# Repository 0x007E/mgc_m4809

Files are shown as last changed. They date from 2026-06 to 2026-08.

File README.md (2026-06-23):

  

# `MGC_module` - ATmega4809

The `ATmega4809` (`mgc_module`) is an adaptable board for the [MeGARCard](https://github.com/0x007e/mgc). The board offers the possibility to control the `MeGARCard` with an [ATmega4809](#additional-information). The board itself is connected to the `MeGARCard` within the pcb-to-pcb connectors (no soldering necessary). With the onboard dip-switches the board voltage can be regulated from `3V3` to `5V`. Also the usage of hardware-/software-`twi` to control the [SSD1306](#additional-information)-display on the megacard can be selected.

> To mount the board on the `MeGARCard` disconnect the power source (`USB-C` connector) or any other used source from the MeGARCard!

| Experience  | Level |
|:---|:---:|
| Soldering | ?% |

# Downloads

| Type | File | Description |
|:---:|:---:|:---|
| Schematic | [pdf](https://github.com/0x007E/mgc_m4809/releases/latest/download/schematic.pdf) / [cadlab](https://cadlab.io/project/30419/main/files) | Schematic files |
| Board | [pdf](https://github.com/0x007E/mgc_m4809/releases/latest/download/pcb.pdf) / [cadlab](https://cadlab.io/project/30419/main/files) | Board file |
| Drill | [pdf](https://github.com/0x007E/mgc_m4809/releases/latest/download/drill.pdf) | Drill file |
| BoM | [xlsx](https://github.com/0x007E/mgc_m4809/releases/latest/download/bom.xlsx) / [html](https://github.com/0x007E/mgc_m4809/releases/latest/download/ibom.html) | Bill of Material as Excel/interactive HTML |
| PCB | [zip](https://github.com/0x007E/mgc_m4809/releases/latest/download/kicad.zip) / [tar](https://github.com/0x007E/mgc_m4809/releases/latest/download/kicad.tar.gz) | KiCAD/Gerber/BoM/Drill files |

# Hardware

The pcb is created with `KiCAD`. All files are built with `github actions` so that they are ready for a production environment.

## PCB

The circuit board is populated on both sides (Top, Bottom). The best way for soldering the `SMD` components is within a vapor phase soldering system and for the `THT` components with a standard soldering system.

### Top Layer

Top Layer

### Bottom Layer

Bottom Layer

# Additional Information

| Type | Link | Description |
|:---:|:---:|:---|
| ATmega4809  | [pdf](https://ww1.microchip.com/downloads/en/DeviceDoc/ATmega4808-4809-Data-Sheet-DS40002173A.pdf) | ATmega4808/4809 Data Sheet |
| SSD1306 | [pdf](https://www.vishay.com/docs/37902/oled128o064dbpp3n00000.pdf) | 128 x 64 Graphic OLED |

---

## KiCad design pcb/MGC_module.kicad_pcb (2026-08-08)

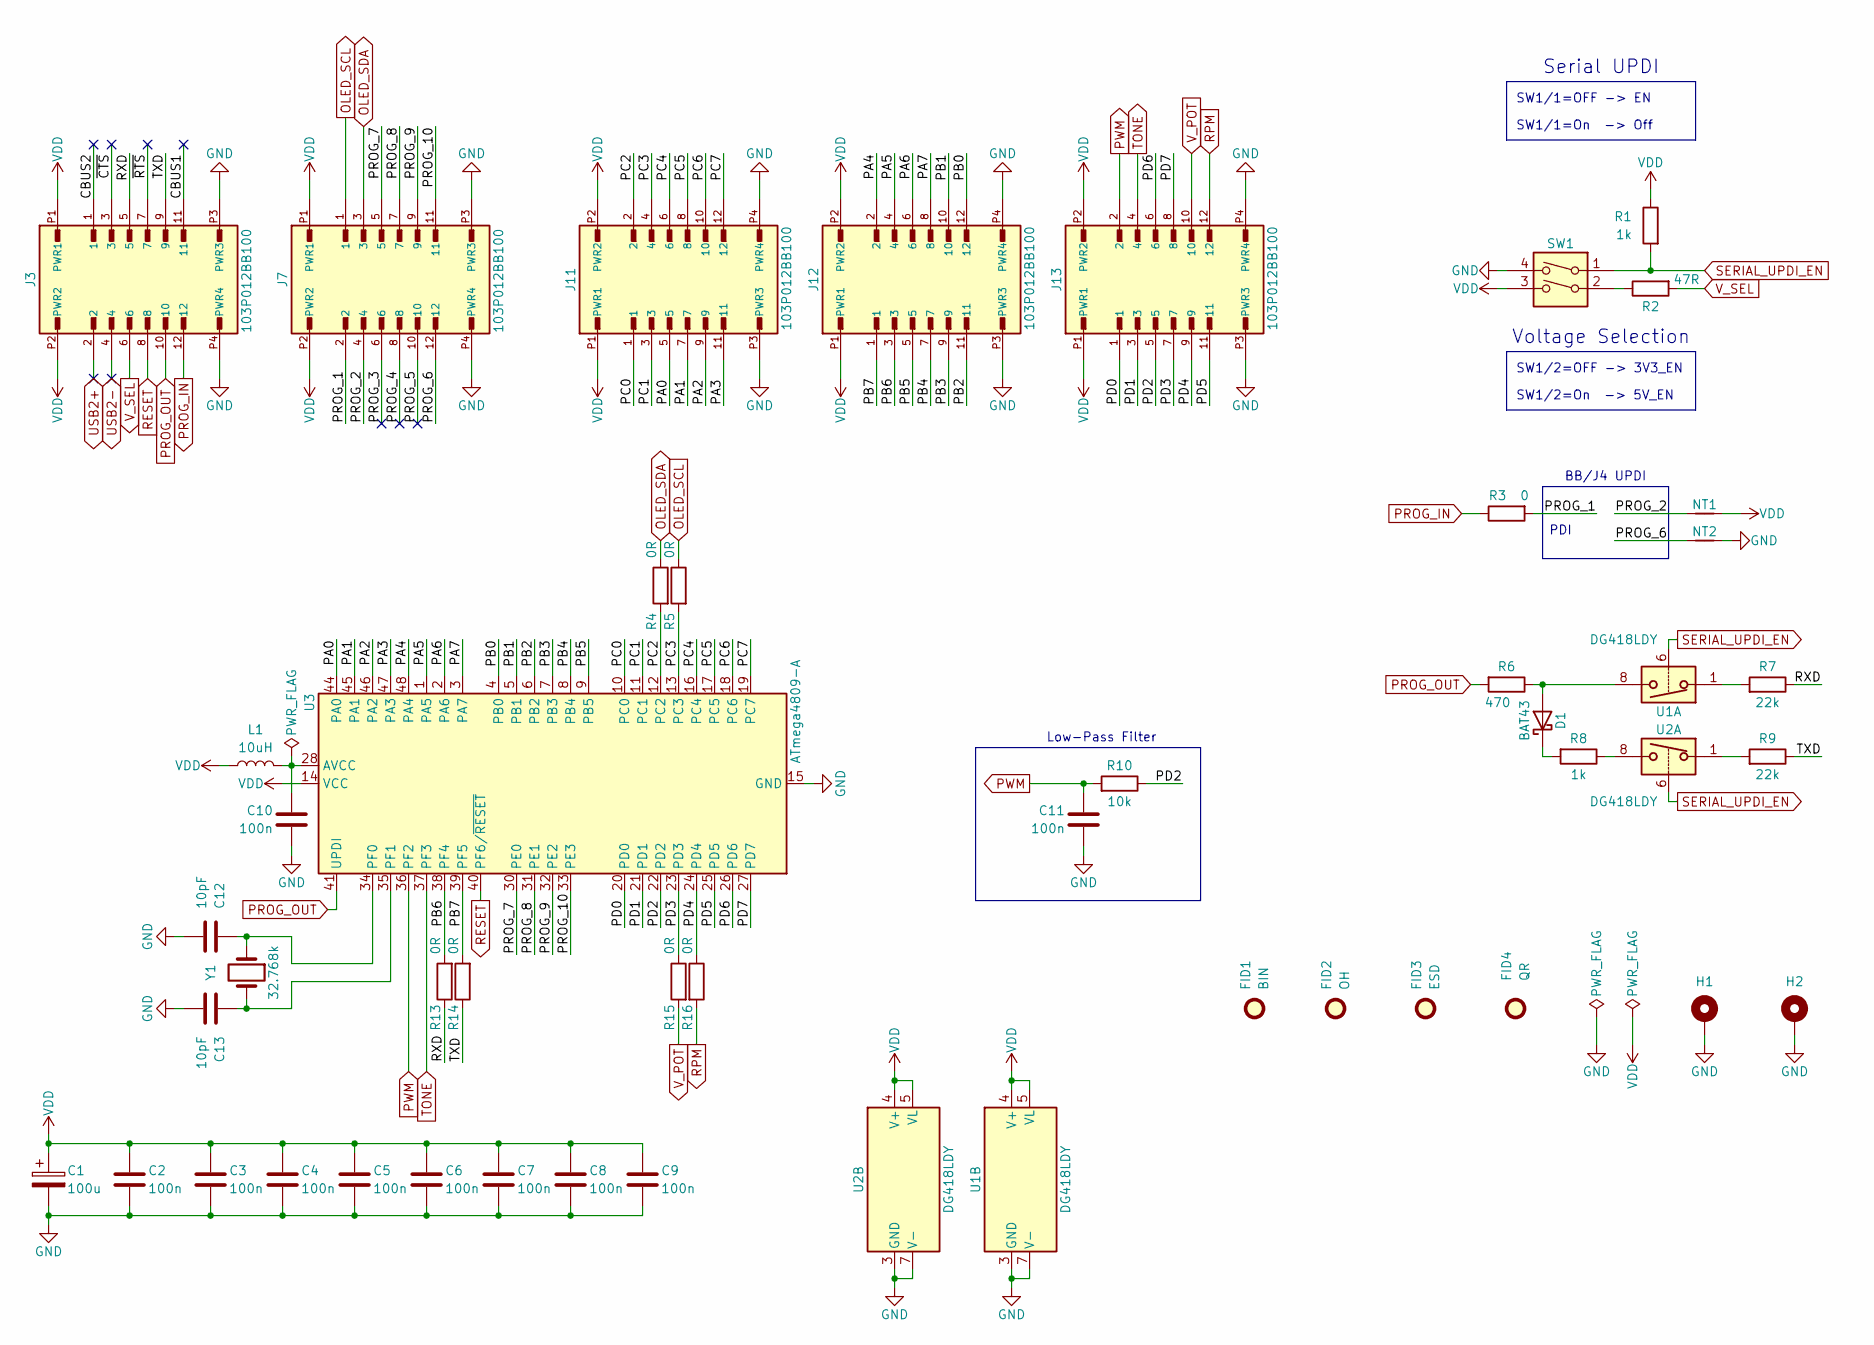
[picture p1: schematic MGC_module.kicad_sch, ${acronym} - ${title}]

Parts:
C1: 100u; CP_EIA-3528-21_Kemet-B; DigiKey 478-3877-1-ND
C2, C3, C4, C5, C6, C7, C8, C9, C10, C11: 100n; C_1206_3216Metric
C12, C13: 10pF; C_0603_1608Metric
D1: BAT43; D_MiniMELF
FID1: BIN; WEEE-Logo_4.2x6mm_SilkScreen
FID2: OH; OSHW-Logo2_7.3x6mm_SilkScreen
FID3: ESD; ESD-Logo_6.6x6mm_SilkScreen
FID4: QR; QR_0x007e_very_small
H1, H2: MountingHole_Pad; MountingHole_2.7mm_M2.5_DIN965_Pad
J3, J7, J11, J12, J13: 103P012BB100; AMPHENOL_103P012BB100; DigiKey 609-103P012BB100CT-ND
L1: 10uH; L_1206_3216Metric
NT1, NT2: NetTie_2; NetTie-2_SMD_Pad0.5mm
R1, R8: 1k; R_1206_3216Metric
R2: 47R; R_1206_3216Metric
R3: 0; R_1206_3216Metric
R4, R5, R13, R14, R15, R16: 0R; R_1206_3216Metric
R6: 470; R_1206_3216Metric
R7, R9: 22k; R_1206_3216Metric
R10: 10k; R_1206_3216Metric
SW1: SW_DIP_x02; SW_DIP_SPSTx02_Slide_6.7x6.64mm_W6.73mm_P2.54mm_LowProfile_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
U1, U2: DG418LDY; SOIC-8_3.9x4.9mm_P1.27mm; DigiKey DG417LEDY-T1-GE4CT-ND
U3: ATmega4809-A; TQFP-48_7x7mm_P0.5mm; DigiKey 150-ATMEGA4809-AURCT-ND
Y1: 32.768k; Crystal_SMD_3215-2Pin_3.2x1.5mm

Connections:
/CBUS1: J3.11
/CBUS2: J3.1
/PA0: J11.5, U3.44 (PA0)
/PA1: J11.7, U3.45 (PA1)
/PA2: J11.9, U3.46 (PA2)
/PA3: J11.11, U3.47 (PA3)
/PA4: J12.2, U3.48 (PA4)
/PA5: J12.4, U3.1 (PA5)
/PA6: J12.6, U3.2 (PA6)
/PA7: J12.8, U3.3 (PA7)
/PB0: J12.12, U3.4 (PB0)
/PB1: J12.10, U3.5 (PB1)
/PB2: J12.11, U3.6 (PB2)
/PB3: J12.9, U3.7 (PB3)
/PB4: J12.7, U3.8 (PB4)
/PB5: J12.5, U3.9 (PB5)
/PB6: J12.3, R13.2, U3.38 (PF4)
/PB7: J12.1, R14.2, U3.39 (PF5)
/PC0: J11.1, U3.10 (PC0)
/PC1: J11.3, U3.11 (PC1)
/PC2: J11.2, R4.2, U3.12 (PC2)
/PC3: J11.4, R5.2, U3.13 (PC3)
/PC4: J11.6, U3.16 (PC4)
/PC5: J11.8, U3.17 (PC5)
/PC6: J11.10, U3.18 (PC6)
/PC7: J11.12, U3.19 (PC7)
/PD0: J13.1, U3.20 (PD0)
/PD1: J13.3, U3.21 (PD1)
/PD2: J13.5, R10.1, U3.22 (PD2)
/PD3: J13.7, R15.1, U3.23 (PD3)
/PD4: J13.9, R16.1, U3.24 (PD4)
/PD5: J13.11, U3.25 (PD5)
/PD6: J13.6, U3.26 (PD6)
/PD7: J13.8, U3.27 (PD7)
/PROG_1: J7.2, R3.2
/PROG_2: J7.4, NT1.1
/PROG_3: J7.6
/PROG_4: J7.8
/PROG_5: J7.10
/PROG_6: J7.12, NT2.1
/PROG_7: J7.5, U3.30 (PE0)
/PROG_8: J7.7, U3.31 (PE1)
/PROG_9: J7.9, U3.32 (PE2)
/PROG_10: J7.11, U3.33 (PE3)
/RXD: J3.5, R7.1, R13.1
/TXD: J3.9, R9.1, R14.1
/~CTS: J3.3
/~RTS: J3.7
GND: C1.2, C2.2, C3.2, C4.2, C5.2, C6.2, C7.2, C8.2, C9.2, C10.2, C11.2, C12.2, C13.2, H1.1, H2.1, J3.P3 (PWR3), J3.P4 (PWR4), J7.P3 (PWR3), J7.P4 (PWR4), J11.P3 (PWR3), J11.P4 (PWR4), J12.P3 (PWR3), J12.P4 (PWR4), J13.P3 (PWR3), J13.P4 (PWR4), NT2.2, SW1.4, U1.3 (GND), U1.7 (V-), U2.3 (GND), U2.7 (V-), U3.15 (GND), U3.29 (GND), U3.43 (GND)
unnamed: D1.2 (A), R6.1, U1.8
unnamed: D1.1 (K), R8.2
unnamed: R2.1, SW1.2
unnamed: R7.2, U1.1
unnamed: R8.1, U2.8
unnamed: R9.2, U2.1
unnamed: C10.1, L1.2, U3.28 (AVCC)
unnamed: C12.1, U3.34 (PF0), Y1.1
unnamed: C13.1, U3.35 (PF1), Y1.2
OLED_SCL: J7.1, R5.1
OLED_SDA: J7.3, R4.1
PROG_IN: J3.12, R3.1
PROG_OUT: J3.10, R6.2, U3.41 (UPDI)
PWM: C11.1, J13.2, R10.2, U3.36 (PF2)
RESET: J3.8, U3.40 (PF6/~RESET)
RPM: J13.12, R16.2
SERIAL_UPDI_EN: R1.2, SW1.1, U1.6, U2.6
TONE: J13.4, U3.37 (PF3)
USB2+: J3.2
USB2-: J3.4
VDD: C1.1, C2.1, C3.1, C4.1, C5.1, C6.1, C7.1, C8.1, C9.1, J3.P1 (PWR1), J3.P2 (PWR2), J7.P1 (PWR1), J7.P2 (PWR2), J11.P1 (PWR1), J11.P2 (PWR2), J12.P1 (PWR1), J12.P2 (PWR2), J13.P1 (PWR1), J13.P2 (PWR2), L1.1, NT1.2, R1.1, SW1.3, U1.4 (V+), U1.5 (VL), U2.4 (V+), U2.5 (VL), U3.14 (VCC), U3.42 (VCC)
V_POT: J13.10, R15.2
V_SEL: J3.6, R2.2

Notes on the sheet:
SW1/2=OFF -> 3V3_EN
SW1/1=OFF -> EN
SW1/2=On -> 5V_EN
SW1/1=On -> Off
Low-Pass Filter
Voltage Selection
PDI
BB/J4 UPDI
Serial UPDI

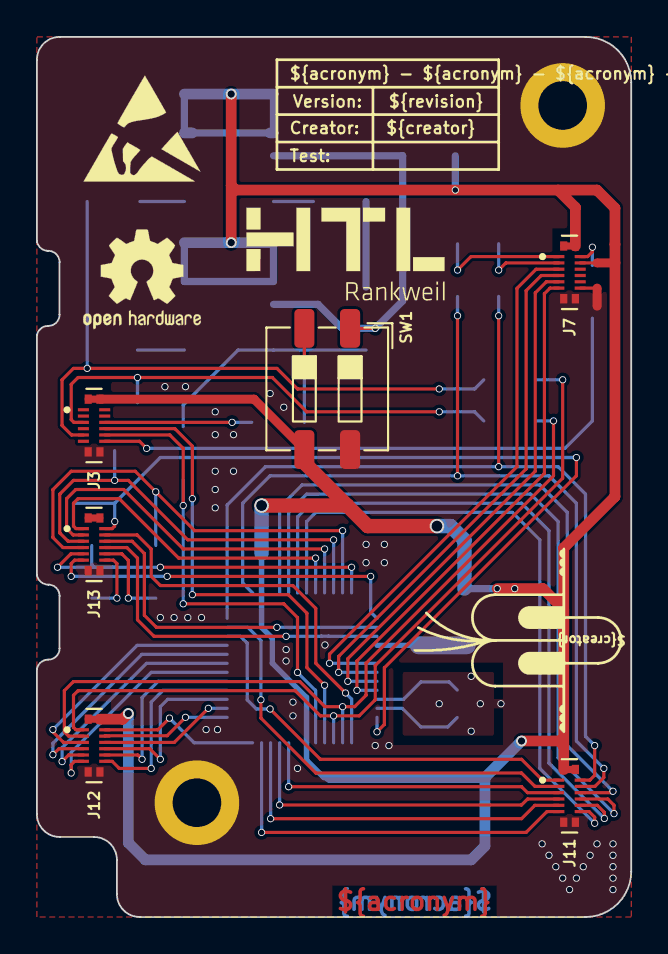
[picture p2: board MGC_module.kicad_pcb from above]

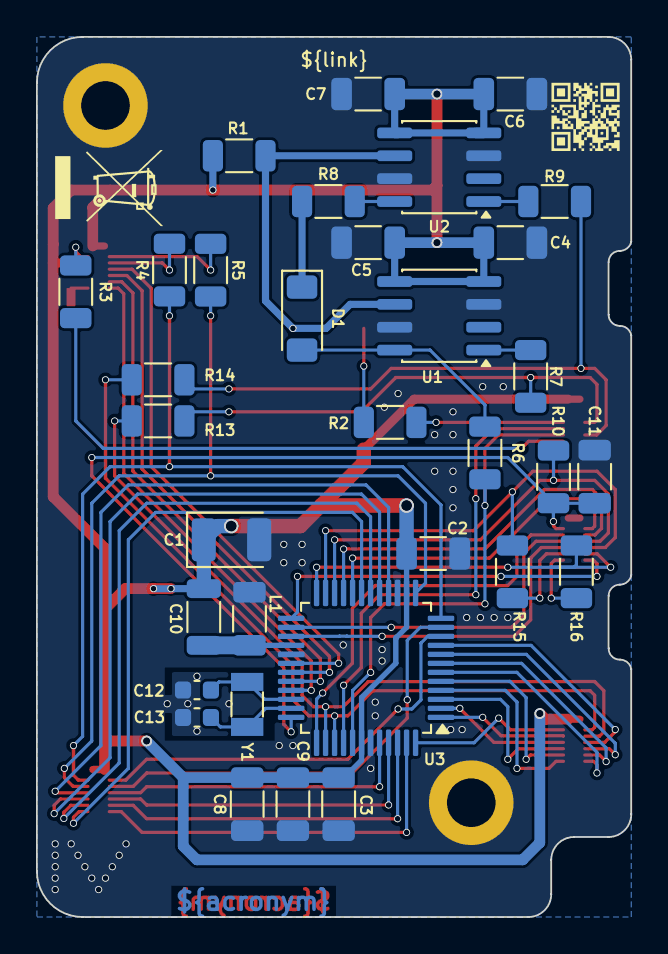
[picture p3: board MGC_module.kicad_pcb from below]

Board: 2 copper layers, 33.0 x 48.9 mm, 47 parts (35 on the bottom side), 63 nets.

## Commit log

2026-06-12 Add pcb layout
    [MGC_module.kicad_pcb, MGC_module.kicad_sch]
2026-06-12 Decrease font size of cu acronym
    [MGC_module.kicad_pcb]
2026-06-18 Fix unconnected labels
    [MGC_module.kicad_pcb, MGC_module.kicad_sch]
2026-06-23 Add missing values in bom
2026-08-08 Fix pwm value/routing issue
    [MGC_module.kicad_pcb, MGC_module.kicad_sch]

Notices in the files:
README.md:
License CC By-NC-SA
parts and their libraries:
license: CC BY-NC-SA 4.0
